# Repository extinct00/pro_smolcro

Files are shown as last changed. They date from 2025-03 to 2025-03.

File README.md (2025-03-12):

# pro_smolcro
Some requirements for this board:
1) Should be a replacement for a pro micro, therefore have the same pinout and should have the same dimensions
2) Have a 5V out from the usb that could be used to either power the other microcontroller or to power some 5v LEDs for better efficiency
3) RP2040 based board with 16MB of flash memory
4) Look into how to detect VUSB from QMK, so i can make sure it works

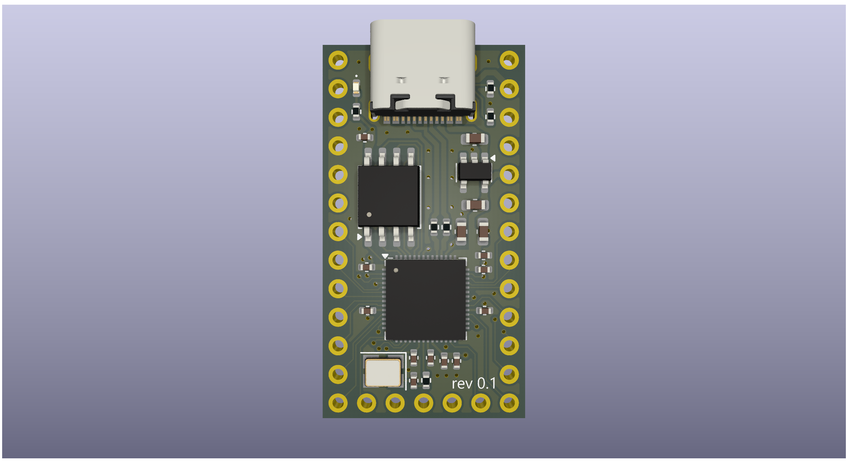
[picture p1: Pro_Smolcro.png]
Pro_Smolcro


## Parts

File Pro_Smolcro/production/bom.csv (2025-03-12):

Designator | Footprint | Quantity | Value | LCSC Part #
C1, C11, C12, C2 | 0603 | 4 | 1u
C10, C13, C3, C4, C5, C6, C7, C8, C9 | 0402 | 9 | 100n
C14, C15 | 0402 | 2 | 15p | C86285
D4 | 0402 | 1 | LED | C130719
J1 | USB_C_Receptacle_G-Switch_GT-USB-7010ASV | 1 | SHOU HAN TYPE-C 16PIN 2MD(073) | C2765186
J2 | PinSocket_1x05_P2.54mm_Vertical | 1 | Conn_01x05
J3, J4 | PinSocket_1x13_P2.54mm_Vertical | 2 | Conn_01x13
R1, R2 | 0402 | 2 | 5.1k
R3, R4 | 0402 | 2 | 27.4 | C2759791
R7 | 0402 | 1 | 1k
R8 | 0402 | 1 | 68R | C2909380
TP4, TP5 | TestPoint_Pad_1.0x1.0mm | 2 | TestPoint
U1 | QFN-56-1EP_7x7mm_P0.4mm_EP3.2x3.2mm | 1 | RP2040 | C2040
U3 | SOIC-8_5.3x5.3mm_P1.27mm | 1 | W25Q128JVS | C97521
U4 | SOT-23-5 | 1 | TLV75733PDBV | C485517
Y1 | Crystal_SMD_3225-4Pin_3.2x2.5mm | 1 | ABM8-272-T3 | C20625731

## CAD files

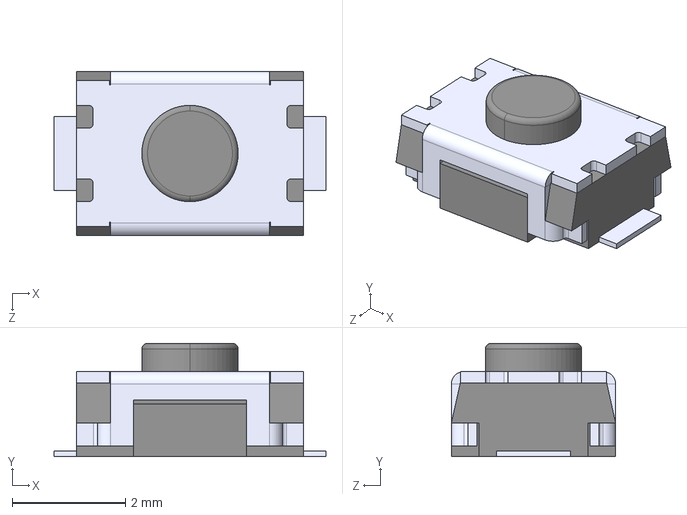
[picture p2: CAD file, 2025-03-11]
Pro_Smolcro/Libs and stuff/TS-1088-AR02016--3DModel-STEP-269445.STEP
4.80 x 2.00 x 2.90 mm

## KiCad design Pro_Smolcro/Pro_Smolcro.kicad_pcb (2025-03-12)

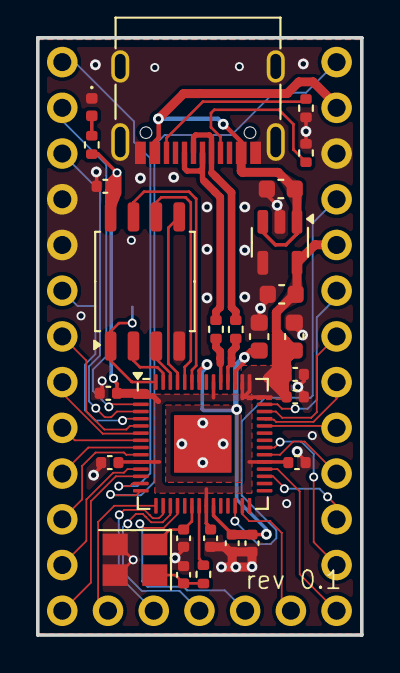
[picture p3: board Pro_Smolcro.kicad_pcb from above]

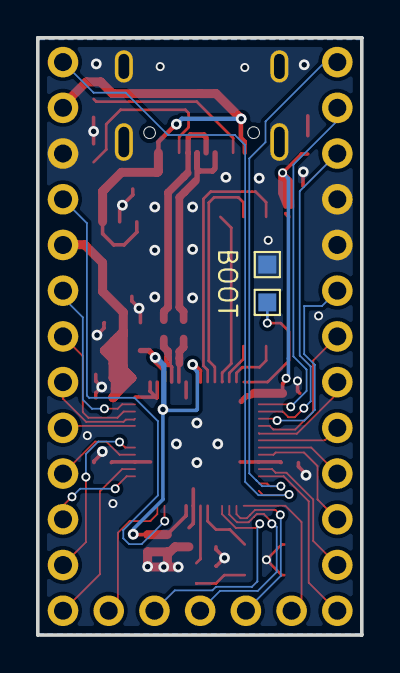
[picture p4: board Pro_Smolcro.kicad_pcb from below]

Board: 2 copper layers, 18.0 x 33.2 mm, 32 parts (2 on the bottom side), 46 nets.

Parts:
C1, C2, C11, C12: 1u; C_0603_1608Metric
C3, C4, C5, C6, C7, C8, C9, C10, C13: 100n; C_0402_1005Metric
C14, C15: 15p; C_0402_1005Metric
D4: LED; LED_0402_1005Metric
J1: SHOU HAN TYPE-C 16PIN 2MD(073); USB_C_Receptacle_G-Switch_GT-USB-7010ASV
J2: Conn_01x05; PinSocket_1x05_P2.54mm_Vertical
J3, J4: Conn_01x13; PinSocket_1x13_P2.54mm_Vertical
R1, R2: 5.1k; R_0402_1005Metric
R3, R4: 27.4; R_0402_1005Metric
R7: 1k; R_0402_1005Metric
R8: 68R; R_0402_1005Metric
TP4, TP5: TestPoint; TestPoint_Pad_1.0x1.0mm
U1: RP2040; QFN-56-1EP_7x7mm_P0.4mm_EP3.2x3.2mm
U3: W25Q128JVS; SOIC-8_5.3x5.3mm_P1.27mm
U4: TLV75733PDBV; SOT-23-5
Y1: ABM8-272-T3; Crystal_SMD_3225-4Pin_3.2x2.5mm

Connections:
3V3: C2.1, C3.1, C4.1, C5.1, C6.1, C7.1, C8.1, C12.1, C13.1, J4.5, R8.1, U1.1 (IOVDD), U1.10 (IOVDD), U1.22 (IOVDD), U1.33 (IOVDD), U1.42 (IOVDD), U1.43 (ADC_AVDD), U1.44 (VREG_IN), U1.48 (USB_VDD), U1.49 (IOVDD), U3.8 (VCC), U4.5 (OUT)
5V: C1.1, J1.A4 (VBUS), J1.A9 (VBUS), J1.B4 (VBUS), J1.B9 (VBUS), J4.2, U4.1 (IN), U4.3 (EN)
+1V1: C9.1, C10.1, C11.1, U1.23 (DVDD), U1.45 (VREG_VOUT), U1.50 (DVDD)
CLK: U1.52 (QSPI_SCLK), U3.6 (CLK)
CS: TP4.1, U1.56 (QSPI_SS), U3.1 (~CS)
D0: U1.53 (QSPI_SD0), U3.5 (DI/IO_{0})
D1: U1.55 (QSPI_SD1), U3.2 (DO/IO_{1})
D2: U1.54 (QSPI_SD2), U3.3 (~WP/IO_{2})
D3: U1.51 (QSPI_SD3), U3.7 (~HOLD/~RESET/IO_{3})
D_N: J1.A7 (D-), J1.B7 (D-), R4.1
D_P: J1.A6 (D+), J1.B6 (D+), R3.1
GND: C1.2, C2.2, C3.2, C4.2, C5.2, C6.2, C7.2, C8.2, C9.2, C10.2, C11.2, C12.2, C13.2, C14.2, C15.2, D4.1 (K), J1.A1 (GND), J1.A12 (GND), J1.B1 (GND), J1.B12 (GND), J1.S1 (SHIELD), J3.4, J3.5, J4.3, R1.2, R2.2, TP5.1, U1.19 (TESTEN), U1.57 (GND), U3.4 (GND), U4.2 (GND), U4.4 (GNDNC), Y1.2, Y1.3
GP0: J3.2, U1.2 (GPIO0)
GP1: J3.3, U1.3 (GPIO1)
GP2: J3.6, U1.4 (GPIO2)
GP3: J3.7, U1.5 (GPIO3)
GP4: J3.8, U1.6 (GPIO4)
GP5: J3.9, U1.7 (GPIO5)
GP6: J3.10, U1.8 (GPIO6)
GP7: J3.11, U1.9 (GPIO7)
GP8: J3.12, U1.11 (GPIO8)
GP9: J3.13, U1.12 (GPIO9)
GP10: J3.1, U1.13 (GPIO10)
GP11: J4.1, U1.14 (GPIO11)
GP12: J2.1, U1.15 (GPIO12)
GP13: J2.2, U1.16 (GPIO13)
GP14: J2.3, U1.17 (GPIO14)
GP15: J2.4, U1.18 (GPIO15)
GP16: J2.5, U1.27 (GPIO16)
GP20: J4.11, U1.31 (GPIO20)
GP21: J4.13, U1.32 (GPIO21)
GP22: J4.10, U1.34 (GPIO22)
GP23: J4.12, U1.35 (GPIO23)
GP26: J4.9, U1.38 (GPIO26_ADC0)
GP27: J4.8, U1.39 (GPIO27_ADC1)
GP28: J4.7, U1.40 (GPIO28_ADC2)
GP29: J4.6, U1.41 (GPIO29_ADC3)
unnamed: C15.1, R7.2, Y1.4
unnamed: D4.2 (A), R8.2
unnamed: J1.A5 (CC1), R1.1
unnamed: J1.B5 (CC2), R2.1
RST: J4.4, U1.26 (RUN)
USBN: R4.2, U1.46 (USB_DM)
USBP: R3.2, U1.47 (USB_DP)
XIN: C14.1, U1.20 (XIN), Y1.1
XOUT: R7.1, U1.21 (XOUT)

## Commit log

2025-03-08 started schematic
    [Pro_Smolcro.kicad_pcb, Pro_Smolcro.kicad_sch]
2025-03-11 finished layout of the main components
    [Pro_Smolcro.kicad_pcb, Pro_Smolcro.kicad_sch, TS-1088-AR02016--3DModel-STEP-269445.STEP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]
2025-03-12 finished the layout
    [Pro_Smolcro.kicad_pcb, Pro_Smolcro.kicad_sch]
2025-03-12 exported gerbers, no panel still tho
    [Pro_Smolcro.kicad_pcb, bom.csv, designators.csv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]
